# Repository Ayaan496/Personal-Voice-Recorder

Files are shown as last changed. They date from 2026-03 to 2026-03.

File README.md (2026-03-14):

A custom from scratch voice recorder.

(Prototype)Hardware: 
- Esp32 S3 Super mini
- I2S omnidirectional Microphone
- Button
- SSD1306 128x64 OLED display

How to Use:
- Currently on the prototype, it is only able to connect through serial. run the python script
  with the main c++ file uploaded to the esp-32 and it should start recording. Click again to
  end the recording and save the data to a recording.wav file.

Future Additions:
- While this is the prototype, the finished version will include an stl file for a
  3d printed casing as well as a kicad schematic for the custom PCB. the final project will have
  its own SD card as well as an option to transfer data through wifi.

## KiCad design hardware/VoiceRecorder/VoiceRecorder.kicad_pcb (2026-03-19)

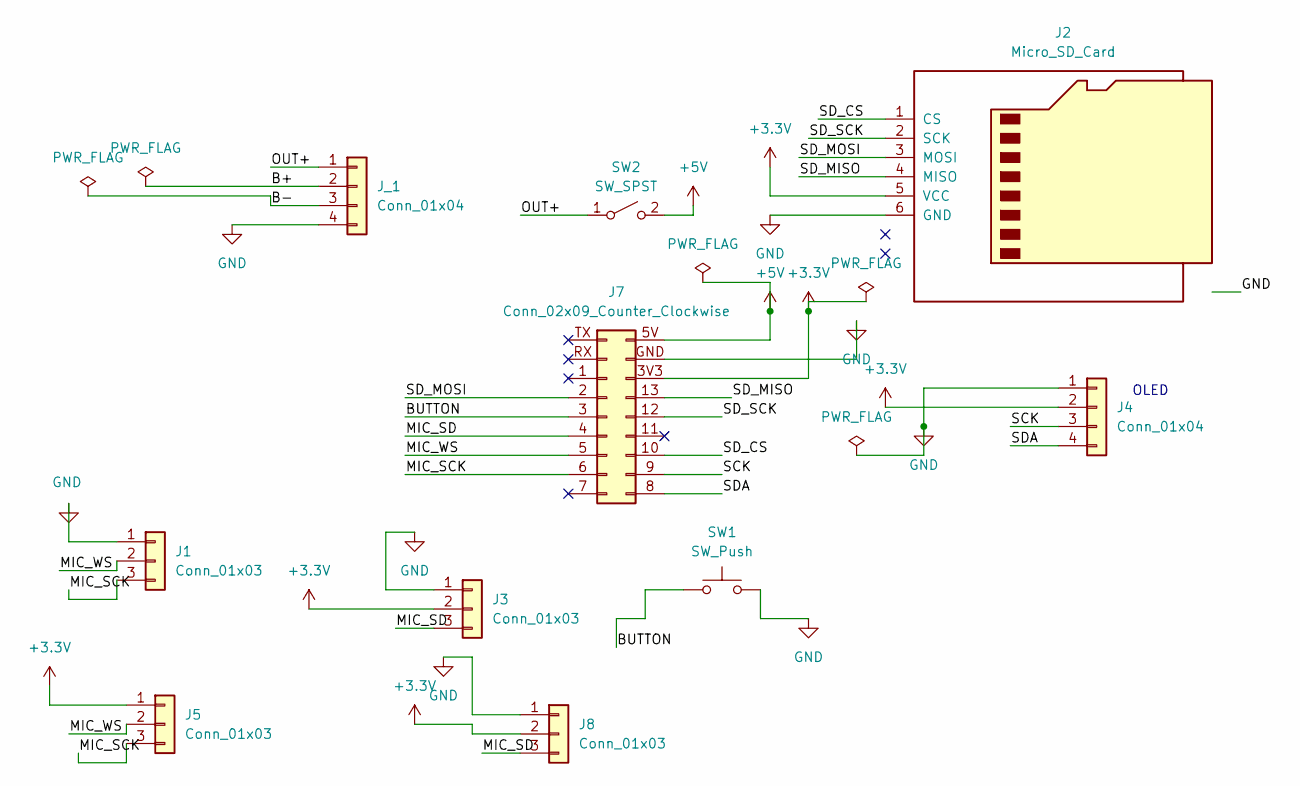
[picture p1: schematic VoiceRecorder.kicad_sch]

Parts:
J1, J3, J5, J8: Conn_01x03; PinHeader_1x03_P2.54mm_Vertical
J2: Micro_SD_Card; PinSocket_1x06_P2.54mm_Horizontal
J4: Conn_01x04; PinHeader_1x04_P2.54mm_Vertical
J7: Conn_02x09_Counter_Clockwise; ESP32-S3-SuperMini
J_1: Conn_01x04; PinHeader_1x04_P2.54mm_Vertical
SW1: SW_Push; SW_Tactile_Straight_KSA0Axx1LFTR
SW2: SW_SPST; PinHeader_1x02_P2.54mm_Vertical

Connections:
+3.3V: J2.5 (VCC), J3.2, J4.2, J5.1, J7.3V3 (Pin_16), J8.2
+5V: J7.5V (Pin_18), SW2.2 (B)
/B+: J_1.2
/B-: J_1.3
/BUTTON: J7.3 (Pin_5), SW1.1
/MIC_SCK: J1.3, J5.3, J7.6 (Pin_8)
/MIC_SD: J3.3, J7.4 (Pin_6), J8.3
/MIC_WS: J1.2, J5.2, J7.5 (Pin_7)
/OUT+: J_1.1, SW2.1 (A)
/SCK: J4.3, J7.9 (Pin_11)
/SDA: J4.4, J7.8 (Pin_10)
/SD_CS: J2.1 (CS), J7.10 (Pin_12)
/SD_MISO: J2.4 (MISO), J7.13 (Pin_15)
/SD_MOSI: J2.3 (MOSI), J7.2 (Pin_4)
/SD_SCK: J2.2 (SCK), J7.12 (Pin_14)
GND: J1.1, J2.6 (GND), J3.1, J4.1, J7.GND (Pin_17), J8.1, J_1.4, SW1.2

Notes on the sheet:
OLED

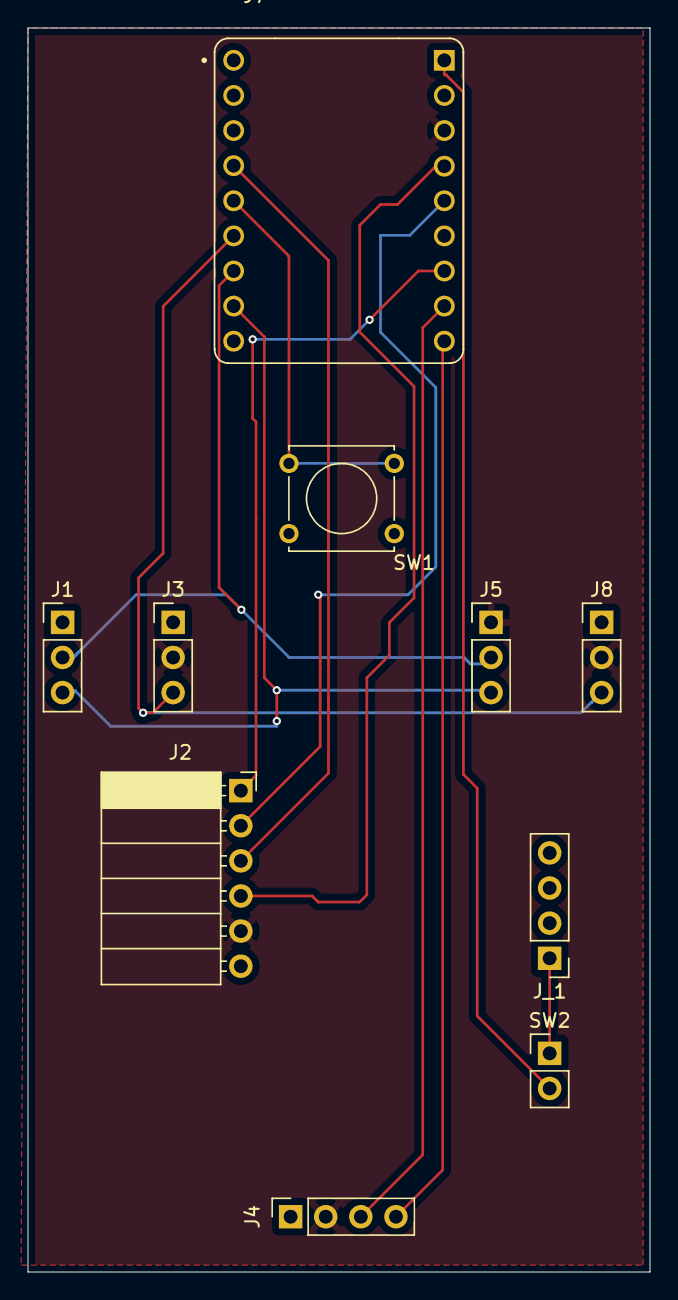
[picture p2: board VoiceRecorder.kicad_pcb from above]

Board: 2 copper layers, 45.0 x 90.0 mm, 10 parts (0 on the bottom side), 14 nets.

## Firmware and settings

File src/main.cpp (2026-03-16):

//Libraries
#include <Arduino.h>
#include <Wire.h>
#include <Adafruit_GFX.h>
#include <Adafruit_SSD1306.h>
#include <driver/i2s.h>
#include <SD.h>
#include <SPI.h>

//Pins
#define SDA_PIN 8
#define SCL_PIN 9
#define I2S_SD_PIN 4
#define I2S_WS_PIN 5
#define I2S_SCK_PIN 6
#define BUTTON_PIN 3

#define SD_CS_PIN 10
#define SD_SCK_PIN 12
#define SD_MOSI_PIN 2
#define SD_MISO_PIN 13

//I2S config
#define I2S_PORT I2S_NUM_0
#define SAMPLE_RATE 16000
#define BUFFER_SIZE 512


//Variables
bool lastButtonState = HIGH;
Adafruit_SSD1306 display(128,64,&Wire, -1);
bool isRecording = false;
int recordingSeconds = 0;
unsigned long lastSecondTick = 0;
int32_t audioBuffer[BUFFER_SIZE];
File audioFile;
int fileIndex = 0;




//I2S setup
void setupI2S(){
  //config struct
  i2s_config_t config = {
    .mode                 = (i2s_mode_t)(I2S_MODE_MASTER | I2S_MODE_RX),//Recieve only
    .sample_rate          = SAMPLE_RATE,
    .bits_per_sample      = I2S_BITS_PER_SAMPLE_32BIT,
    .channel_format       = I2S_CHANNEL_FMT_RIGHT_LEFT,//Stereo, switch to _ONLY_LEFT for mono
    .communication_format = I2S_COMM_FORMAT_STAND_I2S,
    .intr_alloc_flags     = ESP_INTR_FLAG_LEVEL1,
    .dma_buf_count        = 4,
    .dma_buf_len          = BUFFER_SIZE,
    .use_apll             = false,
    .tx_desc_auto_clear   = false,
    .fixed_mclk           = 0
  };

  i2s_pin_config_t pins = {

    .bck_io_num = I2S_SCK_PIN,
    .ws_io_num = I2S_WS_PIN,
    .data_out_num = I2S_PIN_NO_CHANGE, //No data out
    .data_in_num = I2S_SD_PIN

  };

  //I2s activation
  i2s_driver_install(I2S_PORT, &config, 0, NULL);
  i2s_set_pin(I2S_PORT, &pins);
  i2s_start(I2S_PORT);

}

// Write a 32 bit integer to file in little endian
void writeInt32(File &f, int32_t value) {
  f.write((uint8_t*)&value, 4);
}

void writeInt16(File &f, int16_t value) {
  f.write((uint8_t*)&value, 2);
}



void writeWavHeader(File &f, int sampleRate, int numChannels) {
  f.write((const uint8_t*)"RIFF", 4);
  writeInt32(f, 0);
  f.write((const uint8_t*)"WAVE", 4);
  f.write((const uint8_t*)"fmt ", 4);
  writeInt32(f, 16);
  writeInt16(f, 1);
  writeInt16(f, numChannels);
  writeInt32(f, sampleRate);
  writeInt32(f, sampleRate * numChannels * 2);
  writeInt16(f, numChannels * 2);
  writeInt16(f, 16);
  f.write((const uint8_t*)"data", 4);
  writeInt32(f, 0);
}



void finalizeWavHeader(File &f) {
  uint32_t fileSize = f.size();
  uint32_t dataSize = fileSize - 44;  // 44 bytes is the WAV header size

  f.seek(4);
  writeInt32(f, fileSize - 8);  // RIFF chunk size

  f.seek(40);
  writeInt32(f, dataSize);      // data chunk size
}

//display idle screen
void showIdle(){

  display.clearDisplay();
  display.setTextSize(1);
  display.setTextColor(SSD1306_WHITE);
  display.setCursor(0, 0);
  display.println("  Audio Recorder");
  display.drawLine(0, 12, 128, 12, SSD1306_WHITE);
  display.setCursor(0, 20);
  display.println("Tap button to");
  display.println("record audio.");
  display.setCursor(0, 50);
  display.println("Status: IDLE");
  display.display();
}

//display recording screen
void showRecording(int seconds) {
  display.clearDisplay();
  display.setTextSize(1);
  display.setTextColor(SSD1306_WHITE);
  display.setCursor(0, 0);
  display.println("  Audio Recorder");
  display.drawLine(0, 12, 128, 12, SSD1306_WHITE);

    // Flashing REC indicator
  if ((millis() / 500) % 2 == 0) { //fashing circle every half second
    display.fillCircle(6, 28, 5, SSD1306_WHITE);
  }
  display.setTextSize(2);
  display.setCursor(16, 20);
  display.println("REC");

  display.setTextSize(1);
  display.setCursor(0, 44);
  display.print("Time: ");
  display.print(seconds);
  display.println("s");

  display.setCursor(0, 54);
  display.println("Click again to stop");
  display.display();
}
//display saved screen
void showSaved(int seconds, String filename) {
  display.clearDisplay();
  display.setTextSize(1);
  display.setTextColor(SSD1306_WHITE);
  display.setCursor(0, 0);
  display.println("  Audio Recorder");
  display.drawLine(0, 12, 128, 12, SSD1306_WHITE);
  display.setTextSize(2);
  display.setCursor(20, 20);
  display.println("SAVED");
  display.setTextSize(1);
  display.setCursor(0, 44);
  display.print("Duration: ");
  display.print(seconds);
  display.println("s");
  display.setCursor(0, 54);
  display.println(filename);
  display.display();
}

void showError(String message) {
  display.clearDisplay();
  display.setTextSize(1);
  display.setTextColor(SSD1306_WHITE);
  display.setCursor(0, 0);
  display.println("  Audio Recorder");
  display.drawLine(0, 12, 128, 12, SSD1306_WHITE);
  display.setCursor(0, 20);
  display.println("ERROR:");
  display.println(message);
  display.display();
}

void setup() {
  Serial.begin(921600);
  pinMode(BUTTON_PIN, INPUT_PULLUP);
  Wire.begin(SDA_PIN, SCL_PIN);

  //start the display and check if its findable
  if (!display.begin(SSD1306_SWITCHCAPVCC, 0x3C)){
    
    Serial.println("Display not found");
    while(true);
  }

  // Start SPI for SD card
  SPI.begin(SD_SCK_PIN, SD_MISO_PIN, SD_MOSI_PIN, SD_CS_PIN);
  if (!SD.begin(SD_CS_PIN)) {
    showError("SD card not found");
    Serial.println("SD card not found");
    while (true);
  }
  Serial.println("SD card ready");




  setupI2S();
  delay(100);
  lastSecondTick = millis();
  showIdle();
 

}

//send audio data over serial
void sendAudioOverSerial(int32_t* buffer, size_t samples){
  Serial.write((uint8_t*)buffer, samples * sizeof(int32_t));
}

void loop() {

  //Button logic
  bool currentButtonState = digitalRead(BUTTON_PIN);

  if (currentButtonState == LOW && lastButtonState == HIGH) {
    lastButtonState = currentButtonState;
    delay(50); //debounce

    //if button is pressed and not recording, start recording and start counting time
    if (digitalRead(BUTTON_PIN) == LOW) {
      if (!isRecording) {


        // Create a new file with incrementing name e.g. REC001.wav
        String filename = "/REC";
        if (fileIndex < 10) filename += "00";
        else if (fileIndex < 100) filename += "0";
        filename += String(fileIndex) + ".wav";
        fileIndex++;

        audioFile = SD.open(filename, FILE_WRITE);
        if (!audioFile) {
          showError("Cannot open file");
          return;
        }

        writeWavHeader(audioFile, SAMPLE_RATE, 2);


        isRecording = true;
        recordingSeconds = 0;
        lastSecondTick = millis();
        
        Serial.write("START");//send to python script
        showRecording(0);
      } else { //if button pressed and you are recording, stop recording
        isRecording = false;

        finalizeWavHeader(audioFile);
        audioFile.close();

        Serial.println("Recording stopped");
        
        Serial.write("STOP");
        showSaved(recordingSeconds, "/REC" + String(fileIndex - 1) + ".wav");

        delay(2000);
        showIdle();
      }
    }
  }

  lastButtonState = currentButtonState;

  //take data from dma buffer and put it into audio buffer
  if (isRecording) {
    size_t bytesRead = 0;
    i2s_read(I2S_PORT, audioBuffer, sizeof(audioBuffer), &bytesRead, pdMS_TO_TICKS(10));
    //if data was read, send the data over serial
     if (bytesRead > 0) {
      sendAudioOverSerial(audioBuffer, bytesRead / sizeof(int32_t));
      // Convert 32 bit samples to 16 bit and write to SD card
      size_t numSamples = bytesRead / sizeof(int32_t);
      for (size_t i = 0; i < numSamples; i++) {
        int16_t sample = (int16_t)(max(-32768, min(32767, audioBuffer[i] >> 10)));
        audioFile.write((uint8_t*)&sample, 2);
      }

    // Only stream over serial if connected
    if (Serial) {
      sendAudioOverSerial(audioBuffer, bytesRead / sizeof(int32_t));
  }
    }


    //increment recording seconds every second
    if (millis() - lastSecondTick >= 1000) {
      recordingSeconds++;
      lastSecondTick = millis();
      showRecording(recordingSeconds);
    }
  }
}

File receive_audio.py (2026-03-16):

#Libraries
import serial
import wave
import struct
import sys


# Change this to your ESP32's serial port
# Run "ls /dev/ttyUSB*" or "ls /dev/ttyACM*" in terminal to find it
SERIAL_PORT = "/dev/ttyACM0" 
BAUD_RATE = 921600
SAMPLE_RATE = 16000
OUTPUT_FILE = "recording.wav"


#create file and add data
def save_wav(filename,samples,sample_rate):
    with wave.open(filename, 'w') as wav_file:
        wav_file.setnchannels(2) #two for stereo
        wav_file.setsampwidth(2) #16bit per sample
        wav_file.setframerate(sample_rate) #must match esp32 sample rate or else it will be slowed or sped up

        samples_16bit = [max(-32768, min(32767, s >> 10)) for s in samples] #change s >> n for volume and how much the mic picks up, smaller is louder while bigger is quieter
        wav_file.writeframes(struct.pack('<' + 'h' * len(samples_16bit), *samples_16bit))
    print(f"Saved {len(samples_16bit)} samples to {filename}")

def main():
    print(f"Opening {SERIAL_PORT} at {BAUD_RATE} baud...")
    ser = serial.Serial(SERIAL_PORT, BAUD_RATE, timeout=1)
    print("Waiting for recording... press button on ESP32 to start")


    audio_data = []
    recording = False
    buffer = b""
    


    while True:
        chunk = ser.read(512)
        if not chunk:
            continue

        buffer += chunk




        #if detect a start in buffer data, wipe everything before and start from right after the start
        if b"START" in buffer and not recording:
            recording = True
            audio_data = []
            
            buffer = buffer[buffer.index(b"START") + 5:]
            print("Recording started...")


        
        if b"STOP" in buffer and recording:
            stop_index = buffer.index(b"STOP")
            raw = buffer[:stop_index]
            recording = False
            buffer = b""

            # Convert raw bytes to 32 bit integers
            num_samples = len(raw) // 4
            samples = struct.unpack('<' + 'i' * num_samples, raw[:num_samples * 4])
            audio_data.extend(samples)

            print(f"Recording stopped. Saving...")
            save_wav(OUTPUT_FILE, audio_data, SAMPLE_RATE)
            print("Press button again to record another clip")

            # If recording, accumulate full 32 bit samples from buffer
        if recording:
            num_samples = len(buffer) // 4
            if num_samples > 0:
                raw = buffer[:num_samples * 4]
                samples = struct.unpack('<' + 'i' * num_samples, raw)
                audio_data.extend(samples)
                buffer = buffer[num_samples * 4:]

if __name__ == "__main__":
    main()

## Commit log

2026-03-14 Voice Recorder Prototype
2026-03-16 Added SD card capabilities as well as battery powered the prototype. Added Kicad schematic of PCB for the Voice Recorder
    [VoiceRecorder.kicad_pcb, VoiceRecorder.kicad_sch]
2026-03-19 finished pcb design
    [VoiceRecorder-B_Cu.gbr, VoiceRecorder-B_Mask.gbr, VoiceRecorder-B_Paste.gbr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]
